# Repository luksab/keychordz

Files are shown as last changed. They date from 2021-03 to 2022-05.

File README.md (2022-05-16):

# Keychordz

This is my first completely custom keyboard hardware/software.

## Hardware
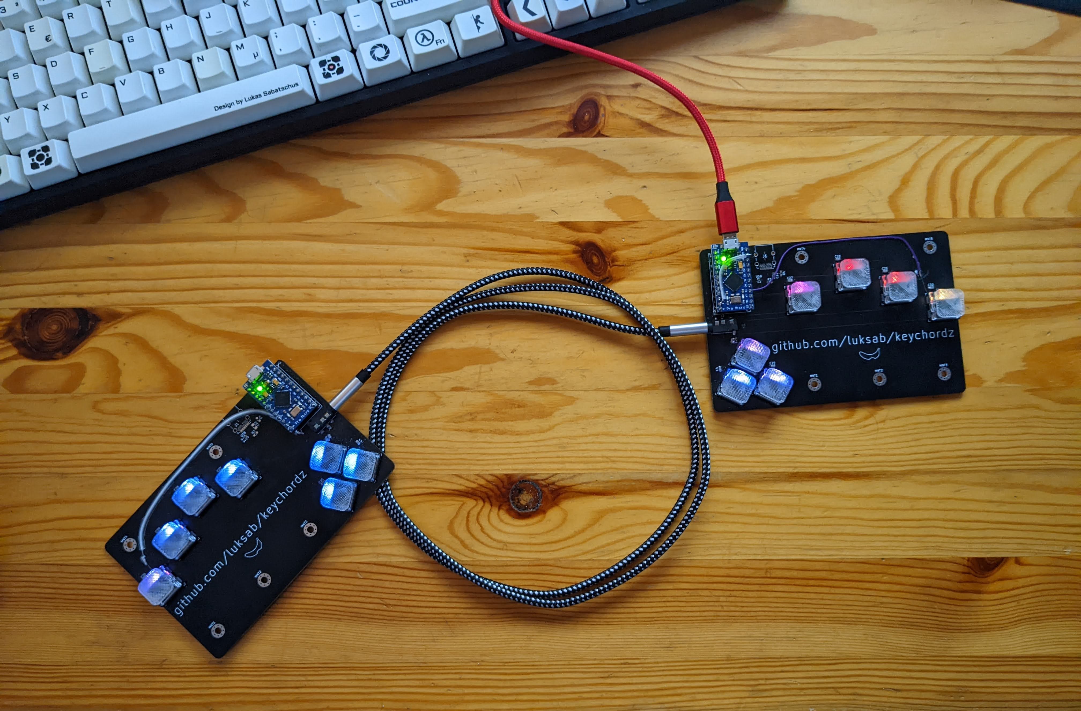
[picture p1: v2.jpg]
Version 2 Hardware


The hardware design is done in [KiCad](https://www.kicad.org/) and can be found in the hardware folder.

## Software

I started configuring [QMK](https://docs.qmk.fm/#/) for this hardware, but the chording features turned out to be too limiting, so I decided to write my own firmware from scratch in [Rust](https://rust-lang.org/).

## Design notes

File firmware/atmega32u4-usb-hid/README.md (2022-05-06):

# Atmega32u4 USB Keyboard Crate

This is a Rust crate for the Atmega32u4 microcontroller. It implements a CDC ACM USB serial device using the [Teensy AVR C library](https://www.pjrc.com/teensy/usb_keyboard.html).

It is adapted from the [atmega32u4-usb-serial](https://github.com/mogenson/atmega32u4-usb-serial) crate.

## To build

Use a nightly compiler version with AVR support by appending `+nightly` to each `cargo` command, or running `rustup override set nightly` once in the crate directory.

Run `cargo build`.

## To use

To upload the `echo.rs` example to a connected Arduino Leonardo board, run `cargo run --example echo`. Open the virtual serial port with a serial terminal and enter lowercase characters. They should be repeated back in uppercase.

Look at `src/lib.rs` and `examples/echo.rs` to see how to use the available USB keyboard methods.

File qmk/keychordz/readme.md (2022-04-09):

# keychordz

keychordz

*A short description of the keyboard/project*

* Keyboard Maintainer: [Lukas Sabatschus](https://github.com/luksab)
* Hardware Supported: *The PCBs, controllers supported*
* Hardware Availability: *Links to where you can find this hardware*

Make example for this keyboard (after setting up your build environment):

    make keychordz:default

Flashing example for this keyboard:

    make keychordz:default:flash

See the [build environment setup](https://docs.qmk.fm/#/getting_started_build_tools) and the [make instructions](https://docs.qmk.fm/#/getting_started_make_guide) for more information. Brand new to QMK? Start with our [Complete Newbs Guide](https://docs.qmk.fm/#/newbs).

## Bootloader

Enter the bootloader in 3 ways:

* **Bootmagic reset**: Hold down the key at (0,0) in the matrix (usually the top left key or Escape) and plug in the keyboard
* **Physical reset button**: Briefly press the button on the back of the PCB - some may have pads you must short instead
* **Keycode in layout**: Press the key mapped to `RESET` if it is available

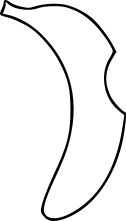
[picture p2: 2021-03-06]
nRF52840Breakout/banana.png

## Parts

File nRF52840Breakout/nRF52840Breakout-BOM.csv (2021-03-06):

Comment | Designator | Footprint | LCSC
nRF52840 | U1 | LGA-73_EP_7.0x7.0x0.5P | C190794

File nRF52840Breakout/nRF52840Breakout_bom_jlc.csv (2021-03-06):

Comment | Designator | Footprint | LCSC Part #
nRF52840 | U1 | Nordic_AQFN-73-1EP_7x7mm_P0.5mm | C190794

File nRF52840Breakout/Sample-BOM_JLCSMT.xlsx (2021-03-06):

Comment | Designator | Footprint | LCSC Part #（optional）
100uF | C1 | CASE-B_3528 | C16133
100nF | C2, C9, C10 | 0603_C | C14663
10uF | C3-5 | 1206_C | C13585
15KΩ | R5, R6 | 0603_R | C22809

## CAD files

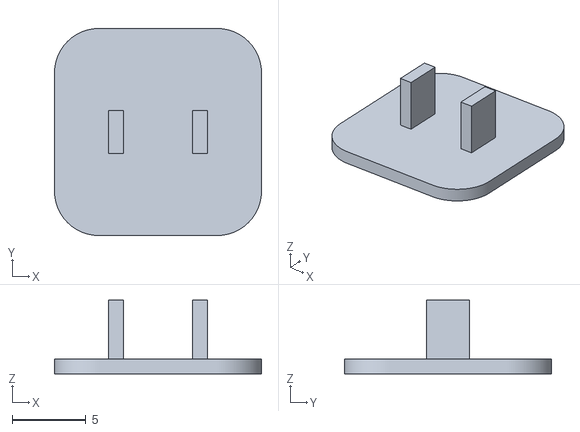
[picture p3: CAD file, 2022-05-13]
ChocCap.stl
14.0 x 14.0 x 5.00

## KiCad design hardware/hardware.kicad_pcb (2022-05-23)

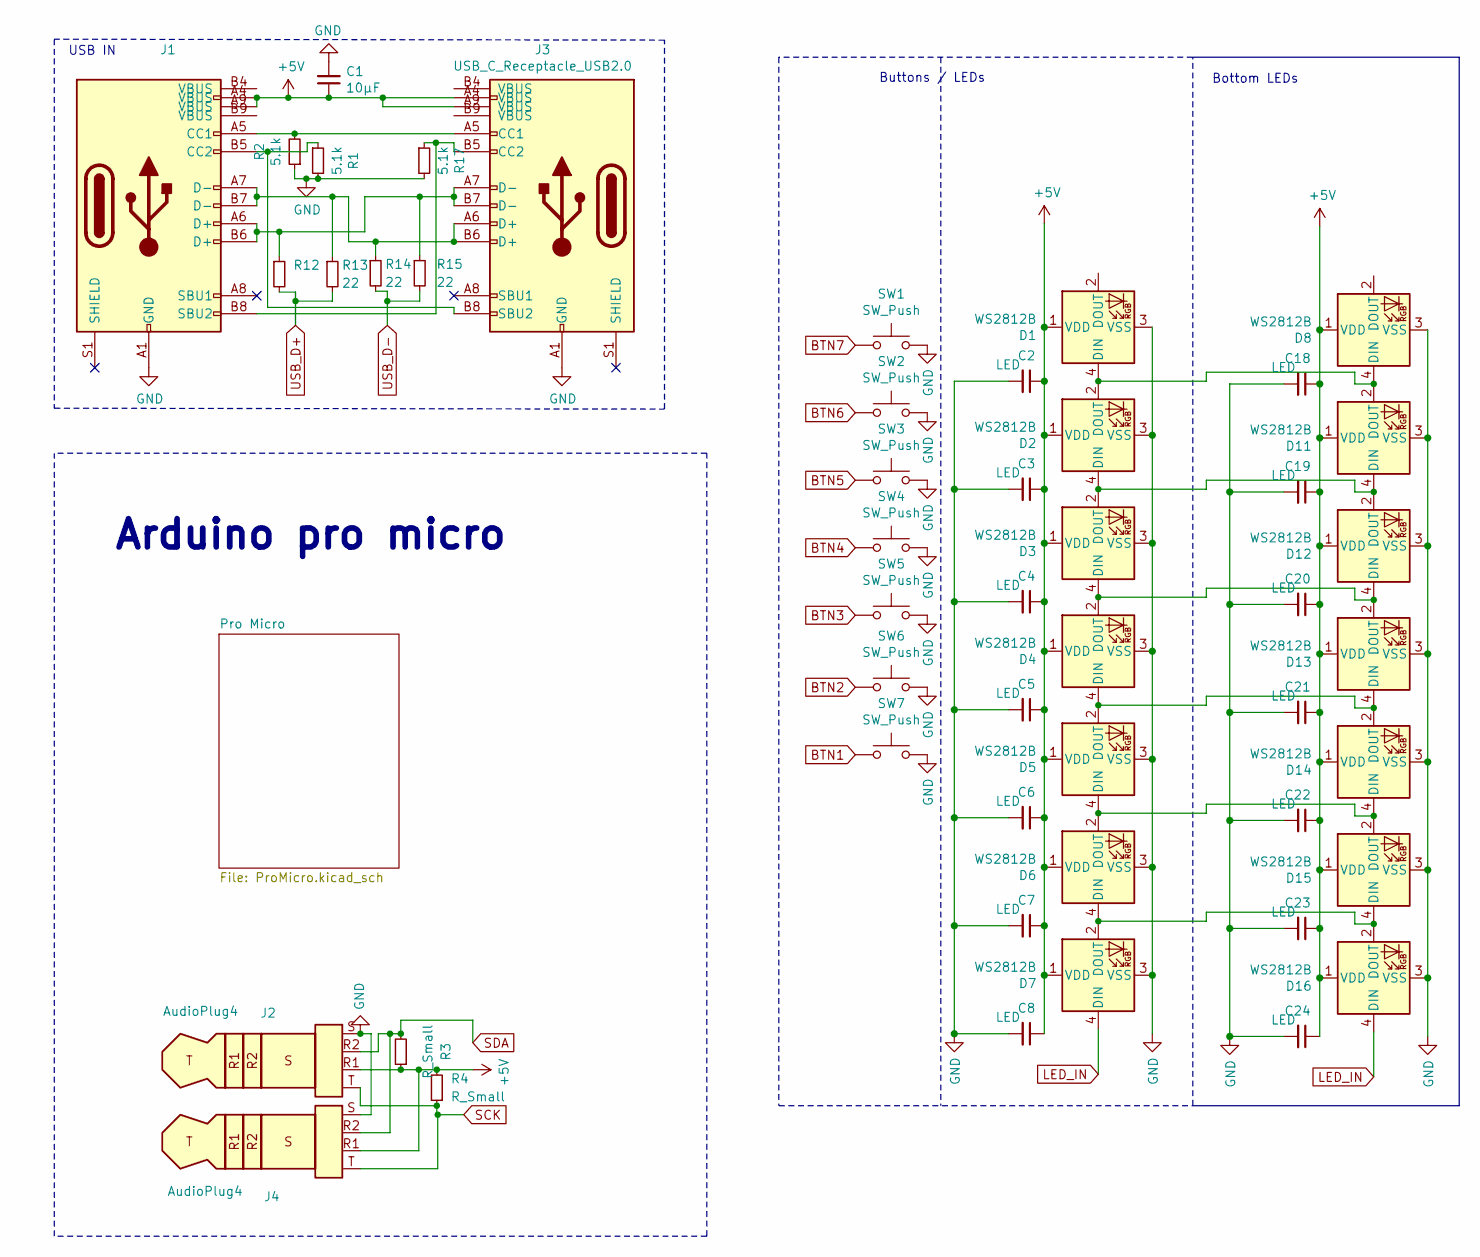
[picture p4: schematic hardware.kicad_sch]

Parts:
C1: 10µF; C_0805_2012Metric_Pad1.18x1.45mm_HandSolder
C2, C3, C4, C5, C6, C7, C8, C18, C19, C20, C21, C22, C23, C24: LED; C_0603_1608Metric_Pad1.08x0.95mm_HandSolder
D1, D2, D3, D4, D5, D6, D7, D8, D11, D12, D13, D14, D15, D16: WS2812B; LED_WS2812B_PLCC4_2.2x2.2mm
J1: (no value)
J2, J4: AudioPlug4; Jack_3.5mm_PJ320D_Horizontal
J3: USB_C_Receptacle_USB2.0; SS52400002
R1, R2, R17: 5.1k; R_0603_1608Metric_Pad0.98x0.95mm_HandSolder
R3, R4: R_Small; R_0603_1608Metric_Pad0.98x0.95mm_HandSolder
R12: (no value)
R13, R14, R15: 22; R_0603_1608Metric_Pad0.98x0.95mm_HandSolder
SW1, SW2, SW3, SW4, SW5, SW6, SW7: SW_Push; SW_PG1350

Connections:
+5V: C1.1, C2.1, C3.1, C4.1, C5.1, C6.1, C7.1, C8.1, C18.1, C19.1, C20.1, C21.1, C22.1, C23.1, C24.1, D1.1 (VDD), D2.1 (VDD), D3.1 (VDD), D4.1 (VDD), D5.1 (VDD), D6.1 (VDD), D7.1 (VDD), D8.1 (VDD), D11.1 (VDD), D12.1 (VDD), D13.1 (VDD), D14.1 (VDD), D15.1 (VDD), D16.1 (VDD), J1.A4 (VBUS), J1.A9 (VBUS), J2.R1, J3.A4 (VBUS), J3.A9 (VBUS), J4.R1, R3.1, R4.2; also elsewhere on the board
BTN1: SW7.1; also elsewhere on the board
BTN2: SW6.1; also elsewhere on the board
BTN3: SW5.1; also elsewhere on the board
BTN4: SW4.1; also elsewhere on the board
BTN5: SW3.1; also elsewhere on the board
BTN6: SW2.1; also elsewhere on the board
BTN7: SW1.1; also elsewhere on the board
GND: C1.2, C2.2, C3.2, C4.2, C5.2, C6.2, C7.2, C8.2, C18.2, C19.2, C20.2, C21.2, C22.2, C23.2, C24.2, D1.3 (VSS), D2.3 (VSS), D3.3 (VSS), D4.3 (VSS), D5.3 (VSS), D6.3 (VSS), D7.3 (VSS), D8.3 (VSS), D11.3 (VSS), D12.3 (VSS), D13.3 (VSS), D14.3 (VSS), D15.3 (VSS), D16.3 (VSS), J1.A1 (GND), J1.A12 (GND), J1.B1 (GND), J1.B12 (GND), J2.S, J3.A1 (GND), J3.A12 (GND), J3.B1 (GND), J3.B12 (GND), J4.S, R1.2, R2.1, R17.2, SW1.2, SW2.2, SW3.2, SW4.2, SW5.2, SW6.2, SW7.2; also elsewhere on the board
LED_IN: D7.4 (DIN), D16.4 (DIN); also elsewhere on the board
unnamed: D1.4 (DIN), D2.2 (DOUT), D8.4 (DIN), D11.2 (DOUT)
unnamed: D2.4 (DIN), D3.2 (DOUT), D11.4 (DIN), D12.2 (DOUT)
unnamed: D3.4 (DIN), D4.2 (DOUT), D12.4 (DIN), D13.2 (DOUT)
unnamed: D4.4 (DIN), D5.2 (DOUT), D13.4 (DIN), D14.2 (DOUT)
unnamed: D6.4 (DIN), D7.2 (DOUT), D15.4 (DIN), D16.2 (DOUT)
unnamed: D5.4 (DIN), D6.2 (DOUT), D14.4 (DIN), D15.2 (DOUT)
unnamed: J1.A5 (CC1), J3.A5 (CC1), R2.2
unnamed: J1.B5 (CC2), J3.B8 (SBU2), R1.1
unnamed: J1.B8 (SBU2), J3.B5 (CC2), R17.1
unnamed 40: J1.A7 (D-), J1.B7 (D-), J3.A6 (D+), J3.B6 (D+), R13.1, R14.1; also elsewhere on the board
unnamed 43: J1.A6 (D+), J1.B6 (D+), J3.A7 (D-), J3.B7 (D-), R12.1, R15.1; also elsewhere on the board
SCK: J2.T, J4.T, R4.1; also elsewhere on the board
SDA: J2.R2, J4.R2, R3.2; also elsewhere on the board
USB_D+: R12.2, R13.2; also elsewhere on the board
USB_D-: R14.2, R15.2; also elsewhere on the board

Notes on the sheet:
Arduino pro micro
Buttons / LEDs
Bottom LEDs
USB IN

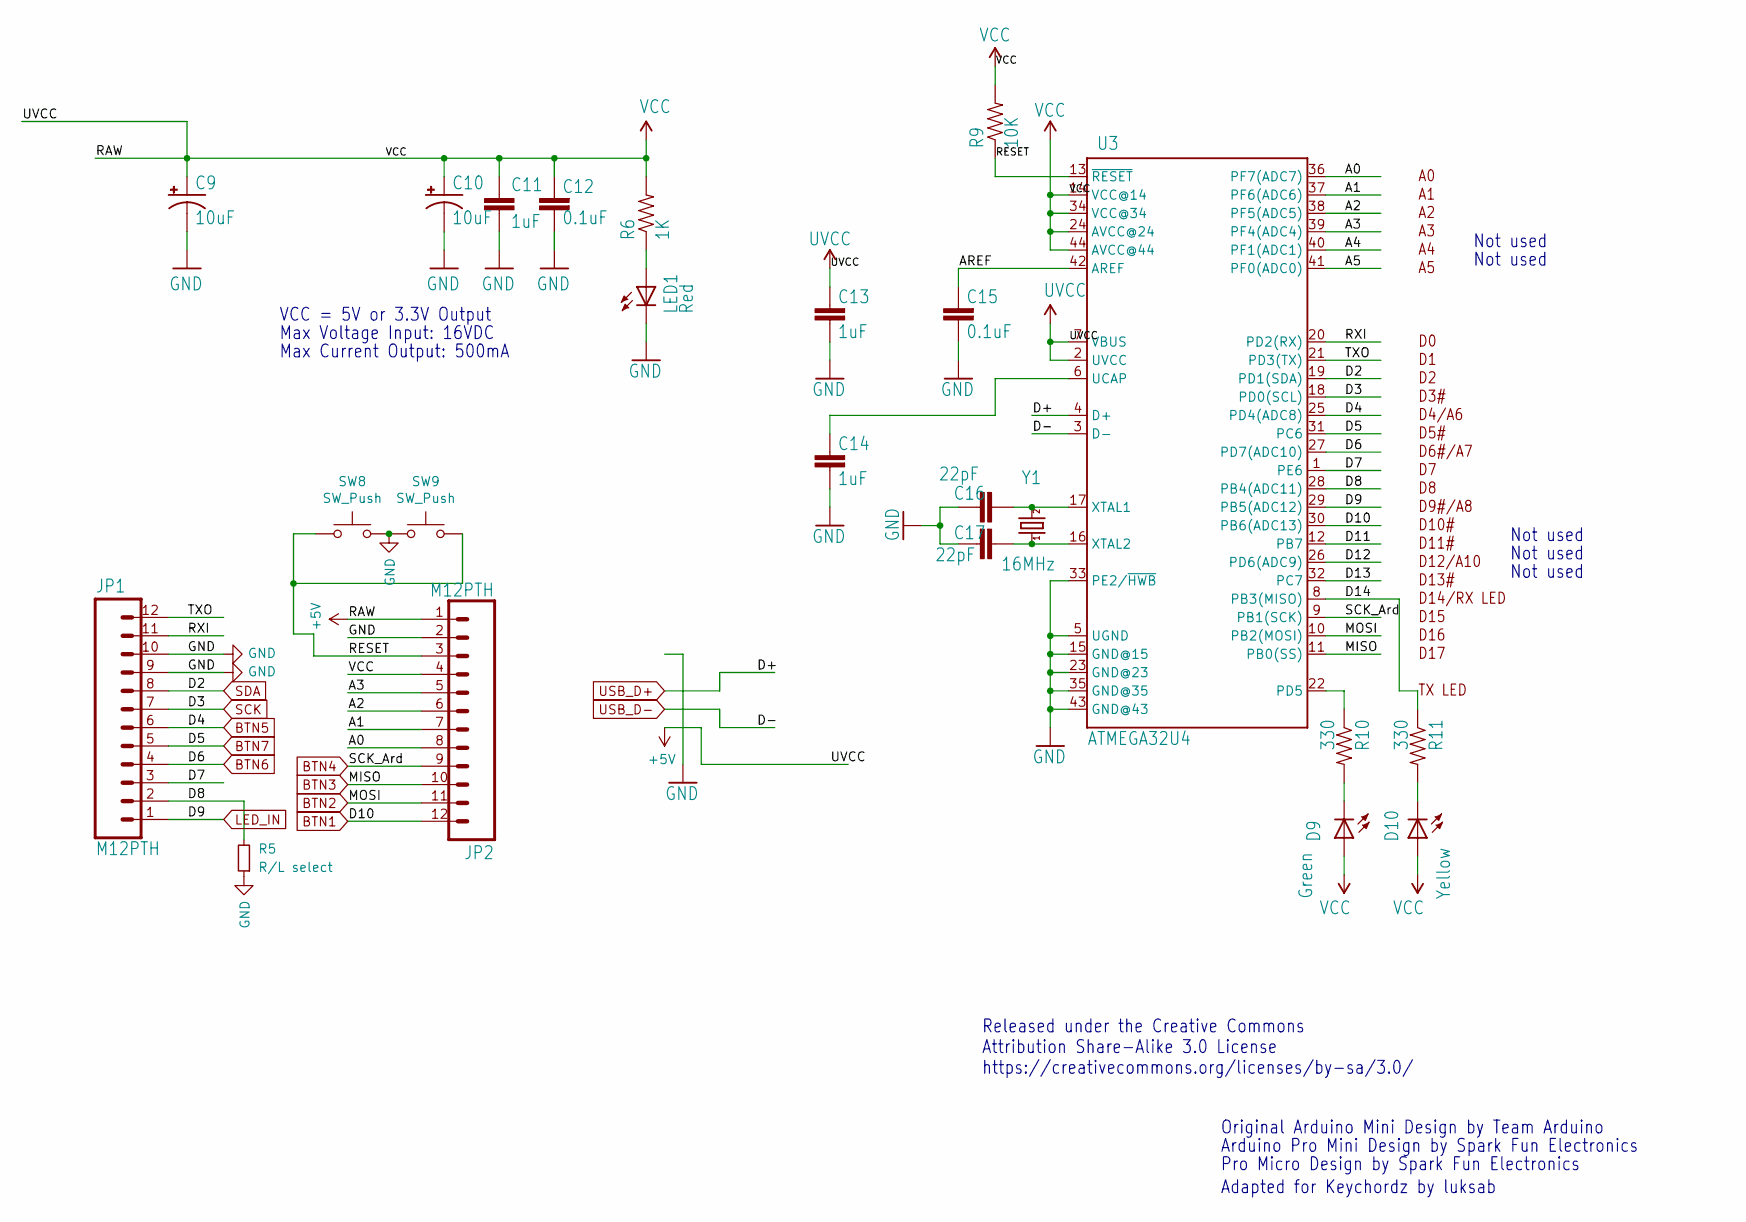
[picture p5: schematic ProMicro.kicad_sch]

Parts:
C9, C10: 10uF; EIA3216
C11, C13, C14: 1uF; C_0603_1608Metric_Pad1.08x0.95mm_HandSolder
C12, C15: 0.1uF; C_0603_1608Metric_Pad1.08x0.95mm_HandSolder
C16, C17: 22pF; C_0603_1608Metric_Pad1.08x0.95mm_HandSolder
D9: Green; LED_0603_1608Metric_Pad1.05x0.95mm_HandSolder
D10: Yellow; LED_0603_1608Metric_Pad1.05x0.95mm_HandSolder
JP1, JP2: M12PTH; PinHeader_1x12_P2.54mm_Vertical
LED1: Red; LED_0603_1608Metric_Pad1.05x0.95mm_HandSolder
R5: R/L select; R_0805_2012Metric_Pad1.20x1.40mm_HandSolder
R6: 1K; R_0603_1608Metric_Pad0.98x0.95mm_HandSolder
R9: 10K; R_0603_1608Metric_Pad0.98x0.95mm_HandSolder
R10, R11: 330; R_0603_1608Metric_Pad0.98x0.95mm_HandSolder
SW8, SW9: SW_Push; SW_SPST_CK_RS282G05A3
U3: ATMEGA32U4; QFN-44-NOPAD_1_1-OUTFAKES
Y1: 16MHz; CRYSTAL-SMD-5X3

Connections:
+5V: C9.A (+), C10.A (+), C11.1, C12.2, C13.2, D9.2 (A), D10.2 (A), JP2.1, JP2.4, R6.2, R9.2, U3.2 (UVCC), U3.7 (VBUS), U3.14 (VCC@14), U3.24 (AVCC@24), U3.34 (VCC@34), U3.44 (AVCC@44); also elsewhere on the board
/Pro Micro/A0: JP2.8, U3.36 (PF7(ADC7))
/Pro Micro/A1: JP2.7, U3.37 (PF6(ADC6))
/Pro Micro/A2: JP2.6, U3.38 (PF5(ADC5))
/Pro Micro/A3: JP2.5, U3.39 (PF4(ADC4))
/Pro Micro/A4: U3.40 (PF1(ADC1))
/Pro Micro/A5: U3.41 (PF0(ADC0))
/Pro Micro/AREF: C15.2, U3.42 (AREF)
/Pro Micro/D7: JP1.3, U3.1 (PE6)
/Pro Micro/D8: JP1.2, R5.2, U3.28 (PB4(ADC11))
/Pro Micro/D11: U3.12 (PB7)
/Pro Micro/D12: U3.26 (PD6(ADC9))
/Pro Micro/D13: U3.32 (PC7)
/Pro Micro/D14: R11.1, U3.8 (PB3(MISO))
/Pro Micro/RESET: JP2.3, R9.1, SW8.1, SW9.2, U3.13 (~RESET)
/Pro Micro/RXI: JP1.11, U3.20 (PD2(RX))
/Pro Micro/TXO: JP1.12, U3.21 (PD3(TX))
BTN1: JP2.12, U3.30 (PB6(ADC13)); also elsewhere on the board
BTN2: JP2.11, U3.10 (PB2(MOSI)); also elsewhere on the board
BTN3: JP2.10, U3.11 (PB0(SS)); also elsewhere on the board
BTN4: JP2.9, U3.9 (PB1(SCK)); also elsewhere on the board
BTN5: JP1.6, U3.25 (PD4(ADC8)); also elsewhere on the board
BTN6: JP1.4, U3.27 (PD7(ADC10)); also elsewhere on the board
BTN7: JP1.5, U3.31 (PC6); also elsewhere on the board
GND: C9.C (-), C10.C (-), C11.2, C12.1, C13.1, C14.1, C15.1, C16.2, C17.2, JP1.9, JP1.10, JP2.2, LED1.1 (C), R5.1, SW8.2, SW9.1, U3.5 (UGND), U3.15 (GND@15), U3.23 (GND@23), U3.33 (PE2/~HWB), U3.35 (GND@35), U3.43 (GND@43); also elsewhere on the board
LED_IN: JP1.1, U3.29 (PB5(ADC12)); also elsewhere on the board
unnamed: C14.2, U3.6 (UCAP)
unnamed: C16.1, U3.17 (XTAL1), Y1.3 (2)
unnamed: C17.1, U3.16 (XTAL2), Y1.1
unnamed: D9.1 (K), R10.2
unnamed: D10.1 (K), R11.2
unnamed: LED1.2 (A), R6.1
unnamed: R10.1, U3.22 (PD5)
SCK: JP1.7, U3.18 (PD0(SCL)); also elsewhere on the board
SDA: JP1.8, U3.19 (PD1(SDA)); also elsewhere on the board
USB_D+: U3.4 (D+); also elsewhere on the board
USB_D-: U3.3 (D-); also elsewhere on the board

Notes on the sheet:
VCC = 5V or 3.3V Output
Arduino Pro Mini Design by Spark Fun Electronics
Original Arduino Mini Design by Team Arduino
Released under the Creative Commons Attribution Share-Alike 3.0 License https://creativecommons.org/licenses/by-sa/3.0/
Pro Micro Design by Spark Fun Electronics
Adapted for Keychordz by luksab
Not used
Max Current Output: 500mA
Max Voltage Input: 16VDC

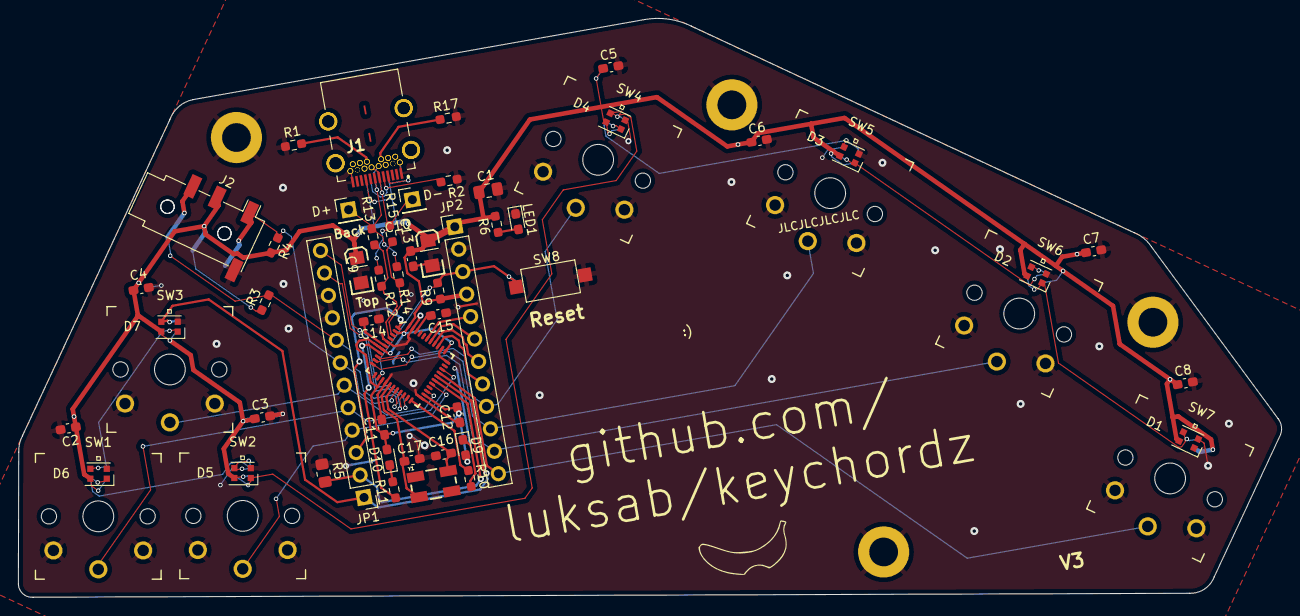
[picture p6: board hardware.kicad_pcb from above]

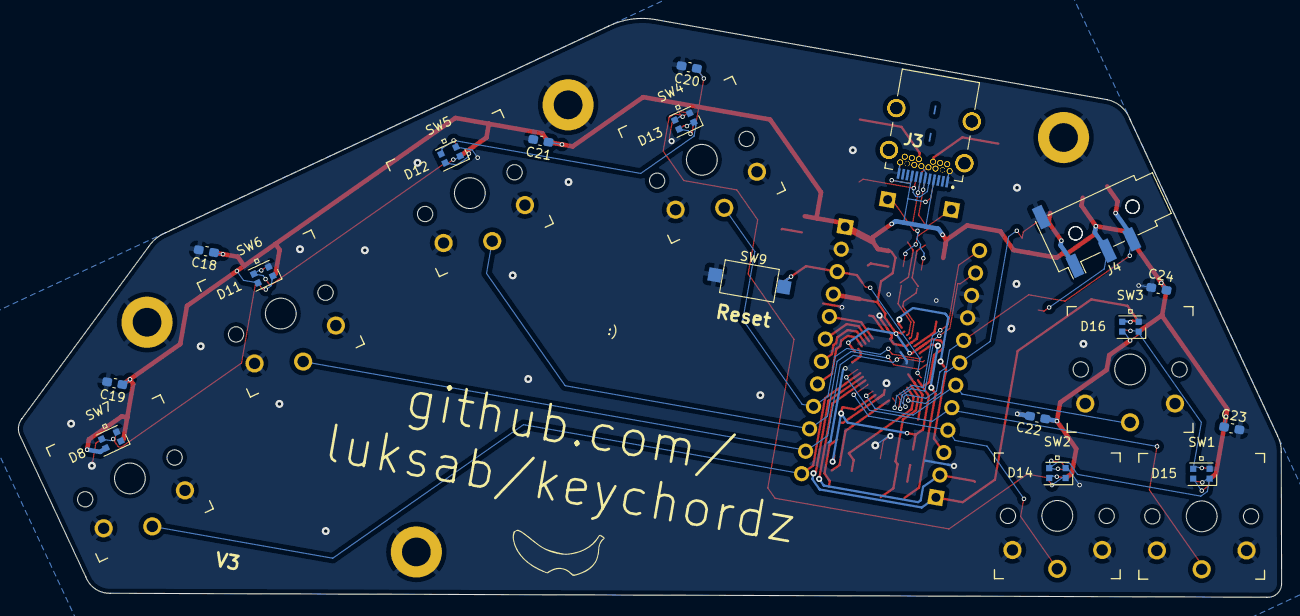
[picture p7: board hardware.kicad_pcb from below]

Board: 2 copper layers, 140.8 x 64.5 mm, 74 parts (17 on the bottom side), 43 nets.

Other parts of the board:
D+: PinHeader_1x01_P2.54mm_Vertical
D-: PinHeader_1x01_P2.54mm_Vertical

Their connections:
unnamed 40: D+.1; also elsewhere on the board
unnamed 43: D-.1; also elsewhere on the board

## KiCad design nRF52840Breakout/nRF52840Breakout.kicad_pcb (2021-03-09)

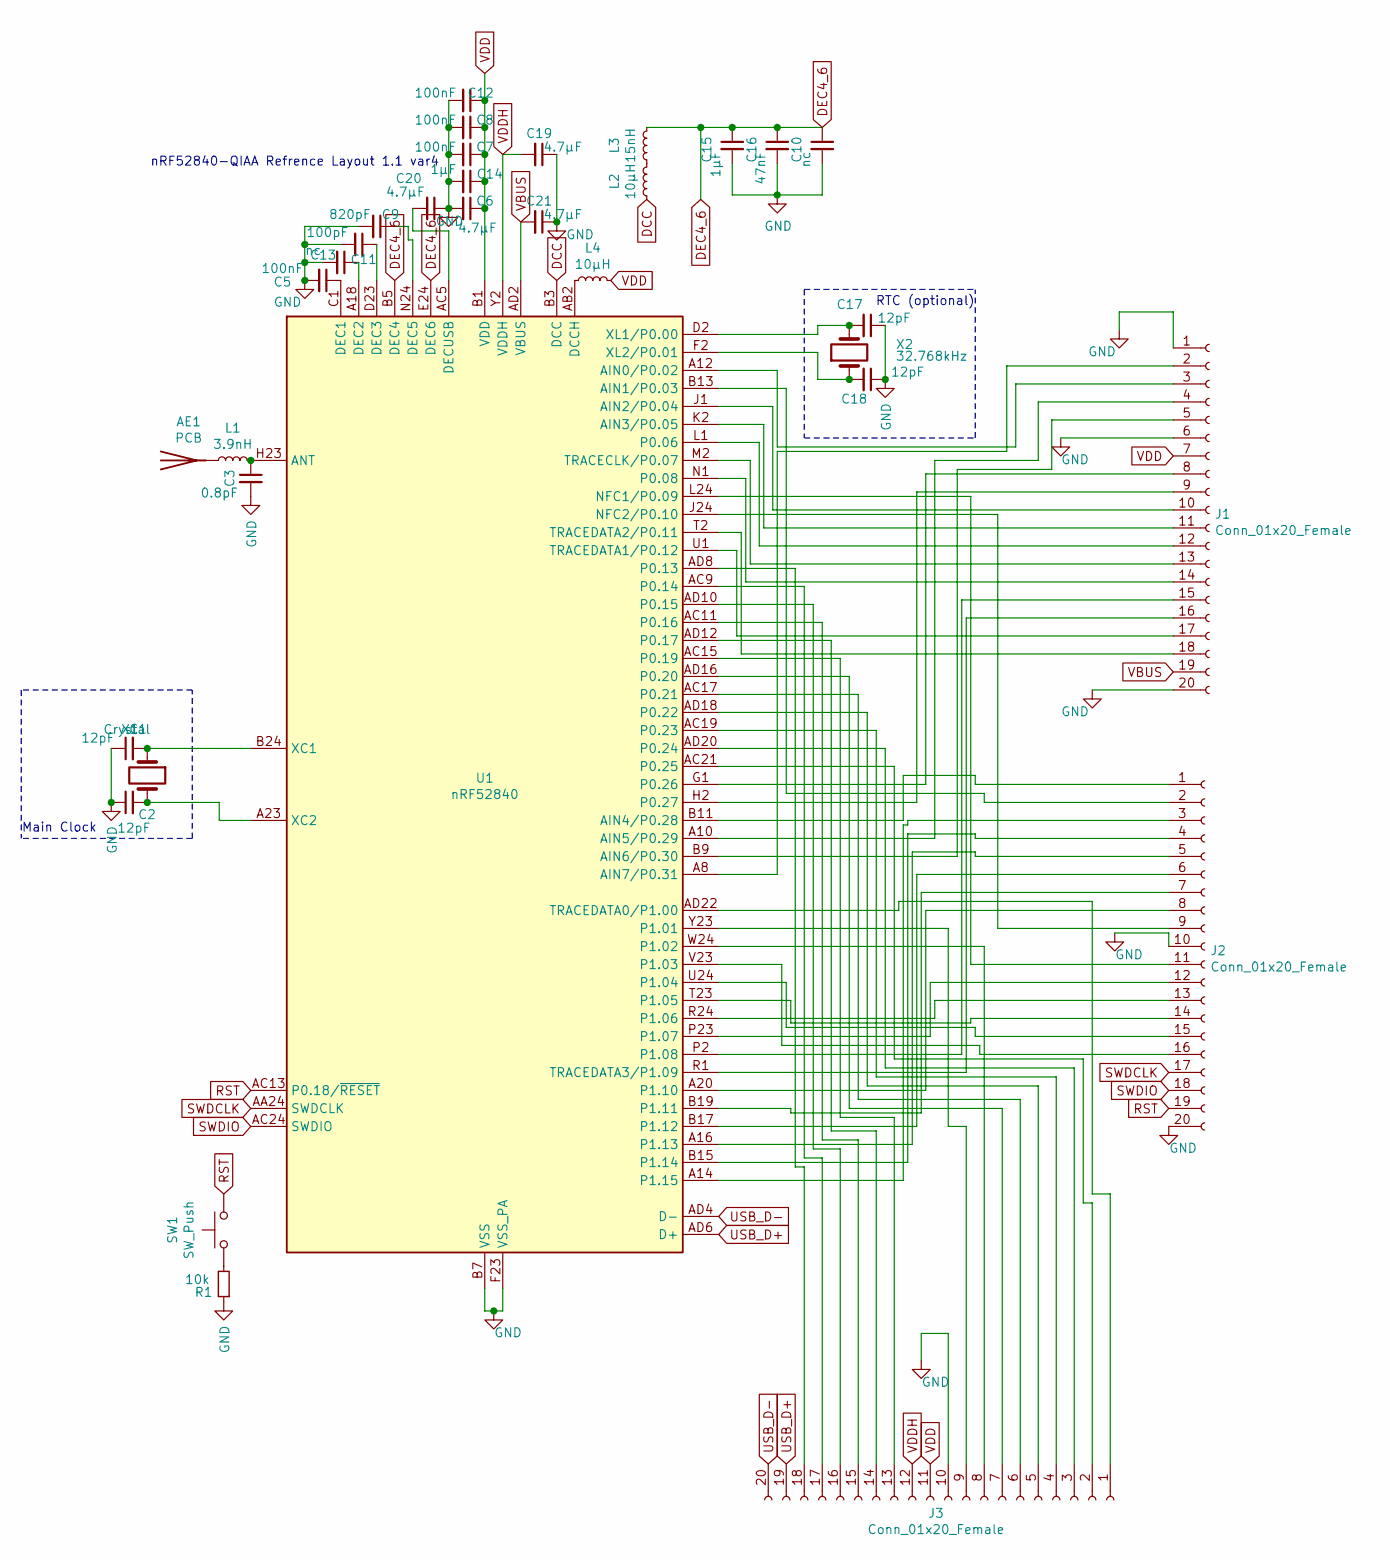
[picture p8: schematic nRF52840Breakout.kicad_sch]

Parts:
AE1: PCB; Texas_SWRA117D_2.4GHz_Left
C1, C2, C17, C18: 12pF; C_0402_1005Metric_Pad0.74x0.62mm_HandSolder
C3: 0.8pF; C_0201_0603Metric_Pad0.64x0.40mm_HandSolder
C5, C7, C8, C12: 100nF; C_0402_1005Metric_Pad0.74x0.62mm_HandSolder
C6, C20: 4.7µF; C_1206_3216Metric_Pad1.33x1.80mm_HandSolder
C9: 820pF; C_0402_1005Metric_Pad0.74x0.62mm_HandSolder
C10, C13: nc; C_0402_1005Metric_Pad0.74x0.62mm_HandSolder
C11: 100pF; C_0603_1608Metric_Pad1.08x0.95mm_HandSolder
C14, C15: 1µF; C_0603_1608Metric_Pad1.08x0.95mm_HandSolder
C16: 47nF; C_0402_1005Metric_Pad0.74x0.62mm_HandSolder
C19, C21: 4.7µF; C_0603_1608Metric_Pad1.08x0.95mm_HandSolder
J1, J2, J3: Conn_01x20_Female; CastelatedHoles 1mm
L1: 3.9nH; L_0402_1005Metric_Pad0.77x0.64mm_HandSolder
L2, L4: 10µH; L_1210_3225Metric_Pad1.42x2.65mm_HandSolder
L3: 15nH; L_0402_1005Metric_Pad0.77x0.64mm_HandSolder
R1: 10k; R_0402_1005Metric_Pad0.72x0.64mm_HandSolder
SW1: SW_Push; SW_SPST_PTS636
U1: nRF52840; Nordic_AQFN-73-1EP_7x7mm_P0.5mm; LCSC C190794
X1: Crystal; XRCGB32M000F2P01R0
X2: 32.768kHz; Crystal_SMD_MicroCrystal_CC7V-T1A-2Pin_3.2x1.5mm_HandSolder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

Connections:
DCC: L2.1, U1.B3 (DCC)
DEC4_6: C10.1, C15.1, C16.1, L3.2, U1.B5 (DEC4), U1.E24 (DEC6)
GND: C1.1, C2.1, C3.2, C5.2, C6.2, C7.2, C8.2, C9.2, C10.2, C11.2, C12.2, C13.2, C14.2, C15.2, C16.2, C17.1, C18.1, C19.1, C20.1, C21.1, J1.1, J1.6, J1.20, J2.10, J2.20, J3.10, R1.1, U1.B7 (VSS), U1.EP (VSS), U1.F23 (VSS_PA)
unnamed: AE1.1 (A), L1.1
unnamed: C1.2, U1.B24 (XC1), X1.1
unnamed: C2.2, U1.A23 (XC2), X1.3
unnamed: C3.1, L1.2, U1.H23 (ANT)
unnamed: C5.1, U1.C1 (DEC1)
unnamed: C9.1, U1.N24 (DEC5)
unnamed: C11.1, U1.D23 (DEC3)
unnamed: C13.1, U1.A18 (DEC2)
unnamed: C17.2, U1.D2 (XL1/P0.00), X2.2
unnamed: C18.2, U1.F2 (XL2/P0.01), X2.1
unnamed: C20.2, U1.AC5 (DECUSB)
unnamed: J1.2, U1.A8 (AIN7/P0.31)
unnamed: J1.3, U1.A12 (AIN0/P0.02)
unnamed: J1.4, U1.A10 (AIN5/P0.29)
unnamed: J1.5, U1.B9 (AIN6/P0.30)
unnamed: J1.8, U1.G1 (P0.26)
unnamed: J1.9, U1.H2 (P0.27)
unnamed: J1.10, U1.J1 (AIN2/P0.04)
unnamed: J1.11, U1.K2 (AIN3/P0.05)
unnamed: J1.12, U1.L1 (P0.06)
unnamed: J1.13, U1.M2 (TRACECLK/P0.07)
unnamed: J1.14, U1.N1 (P0.08)
unnamed: J1.15, U1.P2 (P1.08)
unnamed: J1.16, U1.R1 (TRACEDATA3/P1.09)
unnamed: J1.17, U1.U1 (TRACEDATA1/P0.12)
unnamed: J1.18, U1.T2 (TRACEDATA2/P0.11)
unnamed: J2.1, U1.B11 (AIN4/P0.28)
unnamed: J2.2, U1.B13 (AIN1/P0.03)
unnamed: J2.3, U1.A14 (P1.15)
unnamed: J2.4, U1.B15 (P1.14)
unnamed: J2.5, U1.A16 (P1.13)
unnamed: J2.6, U1.B17 (P1.12)
unnamed: J2.7, U1.B19 (P1.11)
unnamed: J2.8, U1.A20 (P1.10)
unnamed: J2.9, U1.J24 (NFC2/P0.10)
unnamed: J2.11, U1.L24 (NFC1/P0.09)
unnamed: J2.12, U1.P23 (P1.07)
unnamed: J2.13, U1.R24 (P1.06)
unnamed: J2.14, U1.T23 (P1.05)
unnamed: J2.15, U1.U24 (P1.04)
unnamed: J2.16, U1.V23 (P1.03)
unnamed: J3.1, U1.AD22 (TRACEDATA0/P1.00)
unnamed: J3.2, U1.AC21 (P0.25)
unnamed: J3.3, U1.AD20 (P0.24)
unnamed: J3.4, U1.AC19 (P0.23)
unnamed: J3.5, U1.AD18 (P0.22)
unnamed: J3.6, U1.AC17 (P0.21)
unnamed: J3.7, U1.AD16 (P0.20)
unnamed: J3.8, U1.W24 (P1.02)
unnamed: J3.9, U1.Y23 (P1.01)
unnamed: J3.13, U1.AC15 (P0.19)
unnamed: J3.14, U1.AD12 (P0.17)
unnamed: J3.15, U1.AC11 (P0.16)
unnamed: J3.16, U1.AD10 (P0.15)
unnamed: J3.17, U1.AC9 (P0.14)
unnamed: J3.18, U1.AD8 (P0.13)
unnamed: L2.2, L3.1
unnamed: L4.1, U1.AB2 (DCCH)
unnamed: R1.2, SW1.1
RST: J2.19, SW1.2, U1.AC13 (P0.18/~RESET)
SWDCLK: J2.17, U1.AA24 (SWDCLK)
SWDIO: J2.18, U1.AC24 (SWDIO)
USB_D+: J3.19, U1.AD6 (D+)
USB_D-: J3.20, U1.AD4 (D-)
VBUS: C21.2, J1.19, U1.AD2 (VBUS)
VDD: C6.1, C7.1, C8.1, C12.1, C14.1, J1.7, J3.11, L4.2, U1.A22 (VDD), U1.AD14 (VDD), U1.AD23 (VDD), U1.B1 (VDD), U1.W1 (VDD)
VDDH: C19.2, J3.12, U1.Y2 (VDDH)

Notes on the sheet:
Main Clock
nRF52840-QIAA Refrence Layout 1.1 var4
RTC (optional)

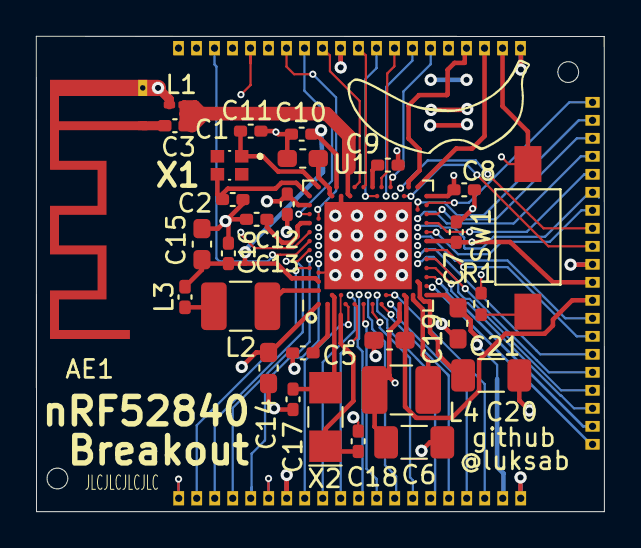
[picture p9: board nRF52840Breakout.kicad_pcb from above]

Board: 4 copper layers, 31.6 x 26.4 mm, 33 parts (0 on the bottom side), 70 nets.

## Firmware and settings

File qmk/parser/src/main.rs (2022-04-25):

use num_enum::{IntoPrimitive, TryFromPrimitive};
use std::{collections::HashSet, fmt, str::FromStr};
use strum::{EnumCount, VariantNames};
use strum_macros::{Display, EnumCount as EnumCountMacro, EnumString, EnumVariantNames};

// [L/R] [Pinkie, Ring, Middle, Index, thumbL, thumbU, thumbD]
#[derive(
    EnumString,
    Display,
    Copy,
    Clone,
    PartialEq,
    Eq,
    Hash,
    PartialOrd,
    Ord,
    IntoPrimitive,
    TryFromPrimitive,
    EnumVariantNames,
    EnumCountMacro,
)]
#[repr(u8)]
enum Finger {
    LP,
    LR,
    LM,
    LI,
    RI,
    RM,
    RR,
    RP,
    LU,
    LD,
    LL,
    RU,
    RD,
    RL,
}

impl fmt::Debug for Finger {
    fn fmt(&self, f: &mut fmt::Formatter) -> fmt::Result {
        write!(f, "{}", self)
    }
}

#[derive(Debug, Clone, PartialEq, Eq, Hash)]
struct Combo {
    fingers: Vec<Finger>,
    key: String,
}

impl fmt::Display for Combo {
    fn fmt(&self, f: &mut fmt::Formatter) -> fmt::Result {
        for (i, finger) in self.fingers.iter().enumerate() {
            if i == 0 {
                write!(f, "{}", finger)?;
            } else {
                write!(f, " {}", finger)?;
            }
        }
        write!(f, " {}", self.key)
    }
}

#[derive(Debug)]
struct Config {
    combos: Vec<Combo>,
}

impl FromStr for Config {
    type Err = String;
    /// format: `([L/R][Pinkie, Ring, Middle, Index, thumbL, thumbU, thumbD]+ [key]\n)+`
    fn from_str(config: &str) -> Result<Self, Self::Err> {
        let mut combos = Vec::new();
        let mut lines = config.lines();
        let mut line_num = 0;
        while let Some(line) = lines.next() {
            line_num += 1;
            if line.starts_with('#') || line.is_empty() {
                continue;
            }
            let mut words = line.split_whitespace();
            let mut fingers = Vec::new();
            let mut key = None;
            while let Some(finger) = words.next() {
                let finger = match Finger::from_str(finger.to_uppercase().as_str()) {
                    Ok(f) => f,
                    Err(_) => {
                        // return Err(format!(
                        //     "Invalid finger name at line {}: {}",
                        //     line_num, finger
                        // ))
                        key = Some(finger.to_uppercase());
                        break;
                    }
                };
                fingers.push(finger);
            }
            if fingers.len() == 0 {
                return Err(format!("Invalid finger on line {}", line_num));
            }
            let key = key.ok_or(format!("Missing Key: line {}", line_num))?;
            // if key.len() != 1 {
            //     return Err(format!(
            //         "Key on line {} must be a single character: {}",
            //         line_num, key
            //     ));
            // }
            combos.push(Combo {
                fingers,
                key: key.to_string(),
            });
        }
        Ok(Config { combos })
    }
}

impl fmt::Display for Config {
    fn fmt(&self, f: &mut fmt::Formatter) -> fmt::Result {
        // don't put a newline at the last line
        for (i, combo) in self.combos.iter().enumerate() {
            if i == self.combos.len() - 1 {
                write!(f, "{}", combo)?;
            } else {
                write!(f, "{}\n", combo)?;
            }
        }
        Ok(())
    }
}

impl Config {
    fn check_dup(&self) -> Result<(), String> {
        let mut finger_set = HashSet::new();
        for combo in &self.combos {
            if !finger_set.insert(combo.fingers.clone()) {
                return Err(format!("Duplicate combo: {}", combo));
            }
        }
        Ok(())
    }

    fn check_dup_in_combo(&self) -> Result<(), String> {
        for combo in &self.combos {
            let mut finger_set = HashSet::new();
            for finger in &combo.fingers {
                if !finger_set.insert(finger.clone()) {
                    return Err(format!("Duplicate finger in combo: {}", combo));
                }
            }
        }
        Ok(())
    }

    fn check_all_single(&self) -> Result<(), String> {
        match self.get_finger_lookup() {
            Ok(_) => Ok(()),
            Err(e) => Err(e),
        }
    }

    fn check(&self) -> Result<(), String> {
        self.check_dup()?;
        self.check_dup_in_combo()?;
        self.check_all_single()?;
        Ok(())
    }
}

impl Config {
    fn get_option_finger_lookup(&self) -> Result<Vec<Option<String>>, String> {
        let mut single_key_lookup = Finger::VARIANTS.iter().map(|_| None).collect::<Vec<_>>();

        for combo in &self.combos {
            if combo.fingers.len() != 1 {
                continue;
            }
            let finger = combo.fingers[0];
            match &single_key_lookup[finger as usize] {
                Some(other_key) => {
                    return Err(format!(
                        "Finger {} is already mapped to {}",
                        finger, other_key
                    ));
                }
                None => {
                    single_key_lookup[finger as usize] = Some(combo.key.clone());
                }
            }
        }

        // single_key_lookup.iter().map(|x| x.unwrap_or(' ')).collect()
        Ok(single_key_lookup)
    }

    fn get_finger_lookup(&self) -> Result<Vec<String>, String> {
        let mut finger_lookup = self.get_option_finger_lookup()?;
        for (i, key) in finger_lookup.iter_mut().enumerate() {
            if key.is_none() {
                return Err(format!(
                    "Finger {} is not mapped",
                    Finger::try_from(i as u8).unwrap()
                ));
            }
        }
        Ok(finger_lookup.into_iter().map(|x| x.unwrap()).collect())
    }

    fn to_keymap(&self) -> Result<String, String> {
        let mut out = String::new();
        out += "[0] = LAYOUT_keychordz(\n";

        let single_key_lookup = self.get_finger_lookup()?;

        out += "   ";
        for (i, key) in single_key_lookup.iter().enumerate() {
            if i == 3 {
                out += &format!("    {},                  ", key);
            } else if i == 7 {
                out += &format!("    {}, \\\n                            ", key);
            } else if i == 10 {
                out += &format!(" {},           ", key);
            } else if i == Finger::COUNT - 1 {
                out += &format!(" {}", key);
            } else if i > 7 {
                out += &format!(" {},", key);
            } else {
                out += &format!("    {},", key);
            }
        }
        out += " \\\n       )";

        Ok(out)
    }

    /// const uint16_t PROGMEM test_combo1[] = {A, S, COMBO_END};
    /// const uint16_t PROGMEM test_combo2[] = {F, H, COMBO_END};
    /// combo_t key_combos[COMBO_COUNT] = {
    ///     COMBO(test_combo1, ESC),
    ///     COMBO(test_combo2, LCTL(Y)), // keycodes with modifiers are possible too!
    /// };
    fn to_qmk_combos(&self) -> Result<String, String> {
        let single_key_lookup = self.get_finger_lookup()?;
        let mut progmem_out = String::new();

        for (i, combo) in self.combos.iter().enumerate() {
            if combo.fingers.len() < 2 {
                continue;
            }
            let mut out = String::new();
            out += &format!("const uint16_t PROGMEM combo_{}[] = {{", i);
            for finger in &combo.fingers {
                out += &format!(" {},", single_key_lookup[*finger as usize]);
            }
            out += " COMBO_END};\n";
            progmem_out += &out;
        }

        let mut key_combos_out = String::new();
        key_combos_out += "combo_t key_combos[COMBO_COUNT] = {\n";
        for (i, combo) in self.combos.iter().enumerate() {
            if combo.fingers.len() < 2 {
                continue;
            }
            let mut out = String::new();
            out += &format!("    COMBO(combo_{}, ", i);
            out += &format!("{}),\n", combo.key);

            key_combos_out += &out;
        }
        key_combos_out += "};\n";

        Ok(format!(
            "{}\n\n{}\n\nComboCount = {}",
            progmem_out,
            key_combos_out,
            self.combos.len() - Finger::COUNT,
        ))
    }
}

fn main() {
    // read filename from first argument
    let file_name = std::env::args().nth(1).unwrap();
    let config = Config::from_str(&std::fs::read_to_string(file_name).unwrap()).unwrap();
    println!("{}", config);
    match config.check() {
        Ok(_) => println!("Config is valid"),
        Err(e) => {
            println!("Config is invalid: {}", e);
            std::process::exit(1);
        }
    }
    println!("{}", config.to_keymap().unwrap());
    println!("{}", config.to_qmk_combos().unwrap());
}

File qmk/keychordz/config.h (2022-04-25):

// Copyright 2022 Lukas Sabatschus (@luksab)
// SPDX-License-Identifier: GPL-2.0-or-later
#pragma once

#include "config_common.h"

#define EE_HANDS
// #define SPLIT_HAND_PIN B4
#define USE_I2C
#define SPLIT_USB_DETECT

#define MATRIX_ROWS 4
#define MATRIX_COLS 4

#define DIRECT_PINS { { C6, D4, D7, E6 }, { B3, B2, B1, NO_PIN } }

#define RGB_DI_PIN B5
#define DRIVER_LED_TOTAL 14
#define RGB_MATRIX_SPLIT { 7, 7 }
#define RGB_MATRIX_KEYPRESSES
#define SPLIT_TRANSPORT_MIRROR
#define SPLIT_LAYER_STATE_ENABLE
#define SPLIT_MODS_ENABLE

#define ENABLE_RGB_MATRIX_CYCLE_LEFT_RIGHT
#define ENABLE_RGB_MATRIX_SOLID_COLOR
#define ENABLE_RGB_MATRIX_BREATHING
#define ENABLE_RGB_MATRIX_CYCLE_LEFT_RIGHT
// #define ENABLE_RGB_MATRIX_PIXEL_FLOW
// #define ENABLE_RGB_MATRIX_SOLID_REACTIVE_MULTIWIDE
#define ENABLE_RGB_MATRIX_SPLASH
#define ENABLE_RGB_MATRIX_MULTISPLASH

#define ENABLE_RGB_MATRIX_SOLID_REACTIVE_SIMPLE
#define RGB_MATRIX_TYPING_HEATMAP_DECREASE_DELAY_MS 50

#define RGB_MATRIX_MAXIMUM_BRIGHTNESS 255

#define RGB_MATRIX_STARTUP_MODE RGB_MATRIX_SOLID_COLOR
#define RGB_MATRIX_STARTUP_VAL 32

#define RGB_MATRIX_KEYPRESSES

#define COMBO_TERM 1000
#define COMBO_COUNT 31

/*
 * Feature disable options
 *  These options are also useful to firmware size reduction.
 */

/* disable debug print */
//#define NO_DEBUG

/* disable print */
//#define NO_PRINT

/* disable action features */
//#define NO_ACTION_LAYER
//#define NO_ACTION_TAPPING
//#define NO_ACTION_ONESHOT

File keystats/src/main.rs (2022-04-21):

use std::{
    collections::HashMap,
    sync::{atomic::AtomicUsize, Arc, RwLock},
};

use colored::Colorize;
use rayon::prelude::*;
use walkdir::{DirEntry, WalkDir};

use structopt::StructOpt;

fn filter_by_extension(extensions: &[&str], entry: &DirEntry) -> bool {
    extensions.iter().any(|ext| {
        entry
            .path()
            .extension()
            .map_or(false, |e| e.to_str() == Some(ext))
    })
}

fn filter_by_not_target(entry: &DirEntry) -> bool {
    !entry
        .path()
        .as_os_str()
        .to_str()
        .map_or(false, |s| s.contains("/target/"))
}

fn file_filter(path: &DirEntry) -> bool {
    let file_exts = vec![
        "rs", "toml", "wgsl", "py", "js", "md", "c", "cpp", "h", "hpp", "html", "css", "sh",
        "java", "go", "ts", "yml", "yaml", "json",
    ];
    filter_by_extension(&file_exts, path) && filter_by_not_target(path)
}

fn str_append_ngram(ngrams: &mut HashMap<Vec<u8>, usize>, s: &[u8], n: usize) {
    for chars in s.windows(n) {
        let mut all_ascii = true;
        for chr in chars {
            all_ascii &= (0..128).contains(chr);
        }
        if !all_ascii {
            // make sure chars are ascii, else continue
            continue;
        }
        // add 1 to element in hashmap
        match ngrams.get_mut(chars) {
            Some(count) => *count += 1,
            None => {
                let _ = ngrams.insert(chars.to_vec(), 1);
            }
        }
    }
}

#[derive(Debug, StructOpt)]
struct Opt {
    /// Enable periodic status updates
    #[structopt(short, long)]
    updates: bool,

    /// Disable sorting by frequency before printing
    #[structopt(short = "s", long)]
    disable_sort: bool,

    /// Print files to process
    #[structopt(short, long)]
    print_files: bool,

    /// The number of ngrams to use
    #[structopt(short, long, default_value = "1")]
    ngrams: usize,

    /// Calculate all n from 1 to ngrams
    #[structopt(short, long)]
    multi: bool,

    /// Output to files beginning with
    #[structopt(short, long)]
    output: Option<String>,

    /// Print stats
    #[structopt(short = "t", long)]
    print_time: bool,

    /// Set which directory to index
    #[structopt(default_value = ".")]
    directory: Vec<String>,
}

fn main() {
    let opt: Opt = Opt::from_args();

    let mut ascii_nums = vec![];
    if opt.multi {
        for _ in 0..opt.ngrams {
            ascii_nums.push(HashMap::new());
        }
    } else {
        ascii_nums.push(HashMap::new());
    }

    let now = Arc::new(RwLock::new(std::time::SystemTime::now()));
    let now_total = std::time::SystemTime::now();
    let num_files = AtomicUsize::new(0);
    let glob = opt
        .directory
        .iter()
        .flat_map(|dir| {
            if !std::path::Path::new(dir).exists() {
                let out = format!("Path \"{}\" does not exist!", dir);
                eprintln!("{}", out.red());
            }
            WalkDir::new(dir)
                .into_iter()
                .filter_map(Result::ok)
                .filter(file_filter)
        })
        .collect::<Vec<_>>();

    if opt.print_files {
        eprintln!("processing files:");
        for file in &glob {
            eprintln!("{}", file.path().display());
        }
    }

    let glob_len = glob.len();
    if opt.print_time {
        eprintln!(
            "Indexing {} files took {:?}",
            glob_len,
            now_total.elapsed().unwrap()
        );
    }

    let now_total = std::time::SystemTime::now();

    glob.iter().for_each(|entry| {
        num_files.fetch_add(1, std::sync::atomic::Ordering::Relaxed);
        // read file to u8 otherwise skip
        let file_content = std::fs::read(entry.path()).unwrap_or(vec![]);
        // count ascii chars
        if opt.multi {
            ascii_nums
                .par_iter_mut()
                .enumerate()
                .for_each(|(i, ascii_num)| {
                    str_append_ngram(ascii_num, &file_content, i + 1);
                });
        } else {
            str_append_ngram(&mut ascii_nums[0], &file_content, opt.ngrams);
        }

        if now.read().unwrap().elapsed().unwrap().as_secs() > 1 && opt.updates {
            let num_processed = num_files.load(std::sync::atomic::Ordering::Relaxed);
            let percent_done = num_processed as f32 / glob_len as f32;
            let time = now_total.elapsed().unwrap().as_secs_f32();
            let eta = (time / percent_done) - time;
            eprintln!(
                "{}/{} files processed. {}% done. ETA: {:?}",
                num_files.load(std::sync::atomic::Ordering::Relaxed),
                glob_len,
                percent_done * 100.,
                std::time::Duration::from_secs_f32(eta)
            );
            *now.write().unwrap() = std::time::SystemTime::now();
        }
    });

    let mut ascii_double_luts = vec![];
    for ascii_num in ascii_nums.iter() {
        let mut ascii_double_lut = vec![];
        for (str, num) in ascii_num.into_iter() {
            if num > &0 && str.iter().all(|chr| (32..127).contains(chr)) {
                ascii_double_lut.push((str, num));
            }
        }
        if !opt.disable_sort {
            ascii_double_lut.sort_by(|a, b| b.1.cmp(&a.1));
        }
        ascii_double_luts.push(ascii_double_lut);
    }
    for (i, ascii_double_lut) in ascii_double_luts.iter_mut().enumerate() {
        let mut output = String::new();
        for (chars, num) in ascii_double_lut {
            // println!(
            //     "{}: {}",
            //     chars.iter().map(|chr| *chr as char).collect::<String>(),
            //     num
            // );
            output.push_str(&format!(
                "{}: {}\n",
                chars.iter().map(|chr| *chr as char).collect::<String>(),
                num
            ));
        }
        match opt.output {
            Some(ref output_file) => {
                std::fs::write(format!("{}_{}.txt", output_file, i + 1), output).unwrap();
            }
            None => {
                if opt.multi {
                    println!("{}gram", i + 1);
                }
                print!("{}", output);
            }
        }
    }

    if opt.print_time {
        eprintln!(
            "Processed {} files in {:?}",
            num_files.load(std::sync::atomic::Ordering::Relaxed),
            now_total.elapsed().unwrap()
        );
    }
}

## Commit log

2021-03-02 schematic first version
    [keychordz.kicad_pcb, keychordz.kicad_sch, keychordz.sch]
2021-03-06 add Breakout
    [Sample-BOM_JLCSMT.xlsx, keychordz.kicad_pcb, keychordz.kicad_sch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]
2021-03-07 keyboard schematic with breakout
    [keychordz-B_Cu.gbr, keychordz-B_Mask.gbr, keychordz-B_Paste.gbr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]
2021-03-08 update breakout without castellations
    [keychordz.kicad_pcb, keychordz.kicad_sch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]
2021-03-09 finish up Schematics
    [keychordz-B_Cu.gbr, keychordz-B_Mask.gbr, keychordz-B_Paste.gbr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]
2021-03-13 change left PCB to STM32
    [keychordz.kicad_pcb, keychordz.kicad_sch]
2021-03-13 change right PCB to STM32
    [keychordz.kicad_pcb, keychordz.kicad_sch]
2021-03-13 change OLED voltage to V_BAT (ordered this commit)
    [keychordz-B_Cu.gbr, keychordz-B_Mask.gbr, keychordz-B_Paste.gbr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]
2022-04-08 use Arduino pro micro
    [keychordz.kicad_pcb, keychordz.kicad_sch]
2022-04-08 fix LED vcc
    [keychordz.kicad_pcb, keychordz.kicad_sch]
2022-04-09 init qmk
    [keychordz-B_Cu.gbr, keychordz-B_Mask.gbr, keychordz-B_Paste.gbr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]
2022-04-11 use pin hand detection
2022-04-15 add keycap stl
    [ChocCap.stl]
2022-04-25 add (incomplete) parser
    [config.cfg]
2022-04-25 allow empty lines and lower case in cfg
2022-04-25 first combo output
    [asentiop.cfg]
2022-04-25 allow keycodes
    [asentiop.cfg]
2022-04-25 full asetniop layout
    [asentiop.cfg]
2022-05-07 add basic led lib
2022-05-07 add (inefficient) "gamma" to led
2022-05-13 adjust chocCap
    [ChocCap.stl]
2022-05-13 optimize led further
2022-05-19 add new hardware rev
    [ProMicro.kicad_sch, hardware.dsn, hardware.kicad_pcb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]
2022-05-20 add backside and rounded corners
    [hardware.kicad_pcb, hardware.kicad_sch]
2022-05-20 start routing
    [hardware.kicad_pcb, hardware.kicad_sch]
2022-05-21 finish routing
    [ProMicro.kicad_sch, hardware.kicad_pcb, hardware.kicad_sch]
2022-05-23 oder V3
    [hardware.kicad_pcb]
2022-06-03 add global print
